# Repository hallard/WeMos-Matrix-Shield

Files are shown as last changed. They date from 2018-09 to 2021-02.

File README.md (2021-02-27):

# Basic ESP8266 WeMos Matrix Shield for Digital Morphing Clock

**This project has been deprecated** please check new version with ESP32 and DMA version [here](https://github.com/hallard/WeMos-Matrix-Shield-DMA)

This shield is used to get simplify ESP8266 connectivity with a [WeMos][22] ESP8266 and nice matric RGB led. This idea came from excellent project called [Morphing Digital Clock][3] done by [HariFun][1] Instructable

See it in action, nice isn't it?

**Pay attention V1.2 got a missing trace between Input and Output connector G1**
See Issue [#2](https://github.com/hallard/WeMos-Matrix-Shield/issues/2). and how to fix. If you have V1.2 don't forget to solder a wire between these 2 points (see below). Thanks to nthonyjclarke and dragondaud for pointing this out



This breakout has just few minimal features.

**New in V1.6**

- added experimetal support for ESP32 boards with WeMos Mini D1 wiring called ESP32 Mini Kit or ESP32 Wemos, or ESP32 MH-ET Live such as this [banggood model](https://www.banggood.com/Wemos-D1-Mini-ESP32-ESP-32-WiFiBluetooth-Internet-Of-Things-Development-Board-Based-ESP8266-p-1205854.html) or this [aliexpress](https://www.aliexpress.com/item/MH-ET-LIVE-D1-mini-ESP32-ESP-32-WiFi-Bluetooth-Internet-of-Things-development-board-based/32815530502.html). But you can find a lot also on ebay, not a problem.
- PCB board has been extented to fit this ESP32 Mini module but also backward compatible with WeMos Mini D1 ESP8266.

Please check wiring and picture before ordering, should looks like something like that:

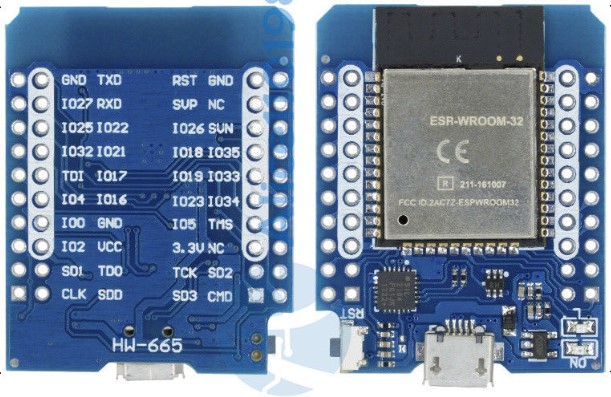
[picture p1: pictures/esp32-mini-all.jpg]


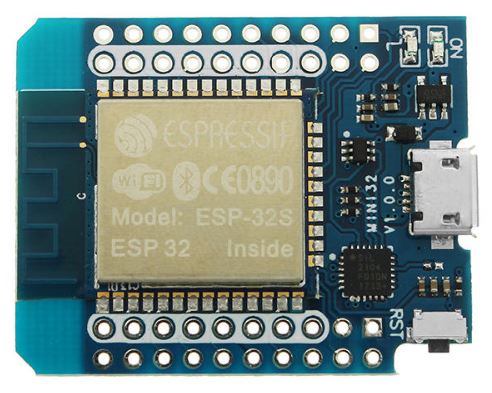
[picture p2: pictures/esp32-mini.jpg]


**New in V1.5**

- changed power connector spacing to fit the same than Matrix one's [#4](https://github.com/hallard/WeMos-Matrix-Shield/issues/4)
- added space for smaller Matrix power connector [#4](https://github.com/hallard/WeMos-Matrix-Shield/issues/4)
- generated [gerbers files](https://github.com/hallard/WeMos-Matrix-Shield/master/gerbers/)

**New in V1.4**

- Added DS18B20 footprint + 4K7 PullUp resistor (DS18B20 DQ connected to GPIO0/D3)
- Removed E connection to add DS18B20 (DQ PIN), added solder jumper if needed this connection back.
- added space for barrel DC connector if connector input connector is top soldered see [#3](https://github.com/hallard/WeMos-Matrix-Shield/issues/3)
- Changed LDR orientation

**New in V1.3**

- Fixed missing trace missing beetwen Input and Output connector G1. That was cutted by accident when creating V1.2 from V1.1.

**New in V1.2**

- Added footprint for a Photoresistor (LDR) + Resistor to be able to adjust luminosity with ambiant light
- This version has a missing trace between Input G0 and Output G1, connect a wire has follow to fix

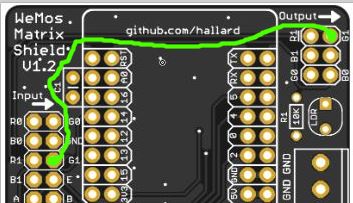
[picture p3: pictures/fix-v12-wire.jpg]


**New in V1.1**

- Power, added big connector 3.5mm spaced to put the supplied power cable
- Changed 3.5mm Phoenix connector by a 5mm one allowing the stronger power cable to fit info
- Moved output connector to the right you can use the supplied flat band connector
- Output connector can go straight to output connector of Matrix, allowing to use a 6 PIN ISP Arduino Like ribbon cable.
- Increased PCB traces width for 5V power
- Added some wiring info on bottom silk

**Still in V1.0+**

- DC Barrel power connector 
- Zero Press Fit power connector
- All necessary headers to connect the Matric Shield

WeMos provide 3 D1, [D1 Mini Lite][20], [D1 Mini][21] or [D1 Mini Pro][22].

**V1.0 boards are tested and working**. But it was missing B1 on 6 pin out connector, so you should grab it elsewhere, but it's now fixed on V1.1+ and also aligned out connector pins to the needed Matrix Order. You can order boards V1.4 at [PCBs.io][4]

# Detailed Description

Look at the schematics for more informations.

# Schematic  

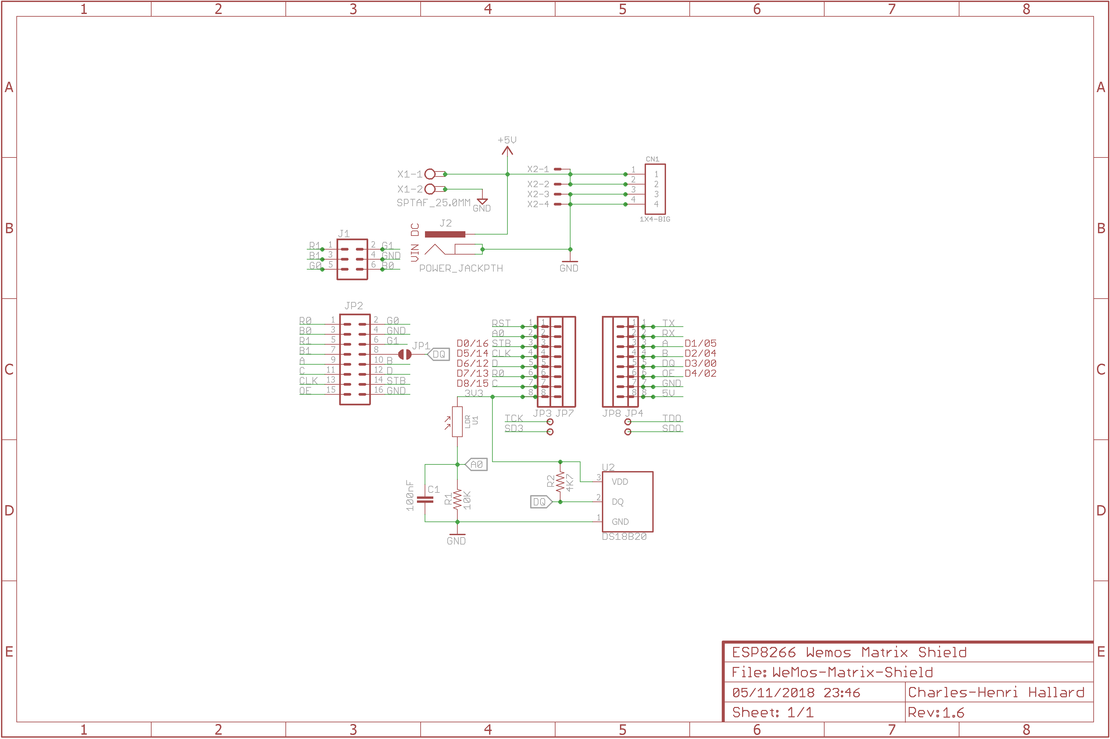
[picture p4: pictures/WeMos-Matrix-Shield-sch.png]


# Boards  

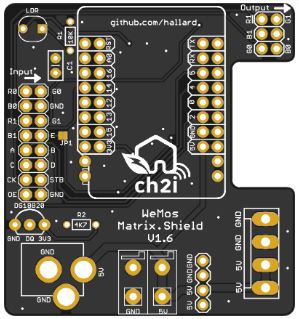
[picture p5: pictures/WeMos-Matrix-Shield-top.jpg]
Top
&nbsp;
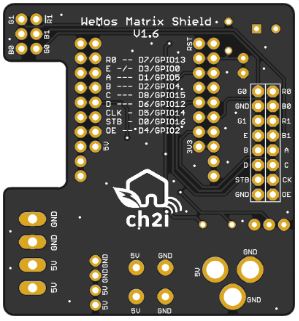
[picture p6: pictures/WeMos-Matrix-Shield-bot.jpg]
Bottom


You can order the PCB of this board at [PCBs.io][4]. PCBs.io give me some reward when you order my designed boards from their site. This is pretty good, because I can use these rewards to create and design new boards and order them for free, so if you don't care about PCB manufacturer please use PCBs.io.

# Firmware

I suggest to use the excellent code done by [dragondaud](https://github.com/dragondaud/myClock), it has all I wanted to do and mandatory feature, OTA and LDR Luminosity management.

# Assembled boards

Board have been made to be plugged directly on the matrix shield, see picture below:

Theese are pictures of the 1st PCB V1.0 with LDR Live Fix, just to see how are connected wire, I'm waiting new boards (V1.3), to take new pictures and show easier connecting.

**2x8 pins female connector is soldered on the bottom side of PCB**

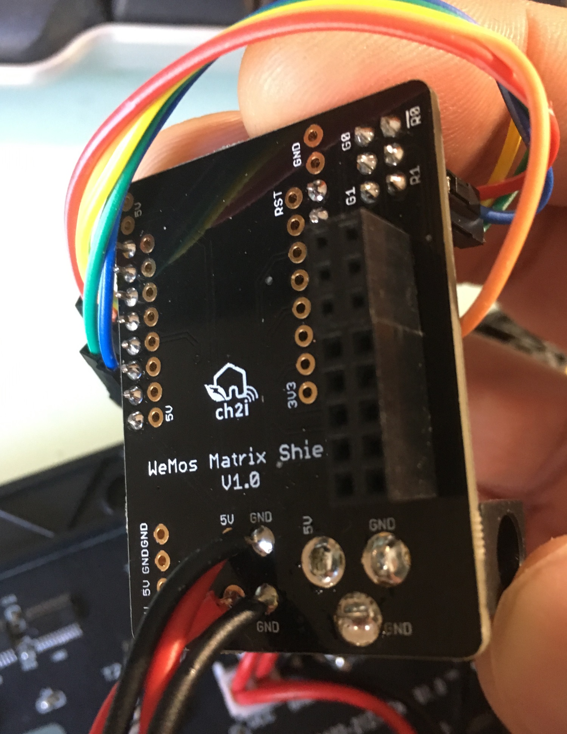
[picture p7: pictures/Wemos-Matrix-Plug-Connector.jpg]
Plug connector


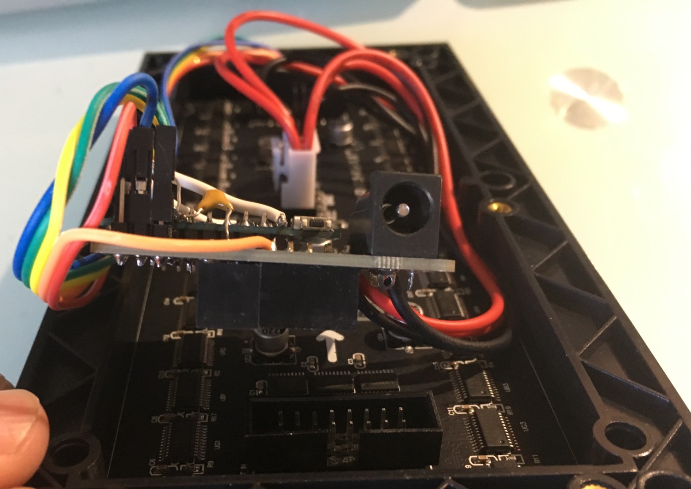
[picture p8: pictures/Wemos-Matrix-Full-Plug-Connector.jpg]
Plug connector on matrix


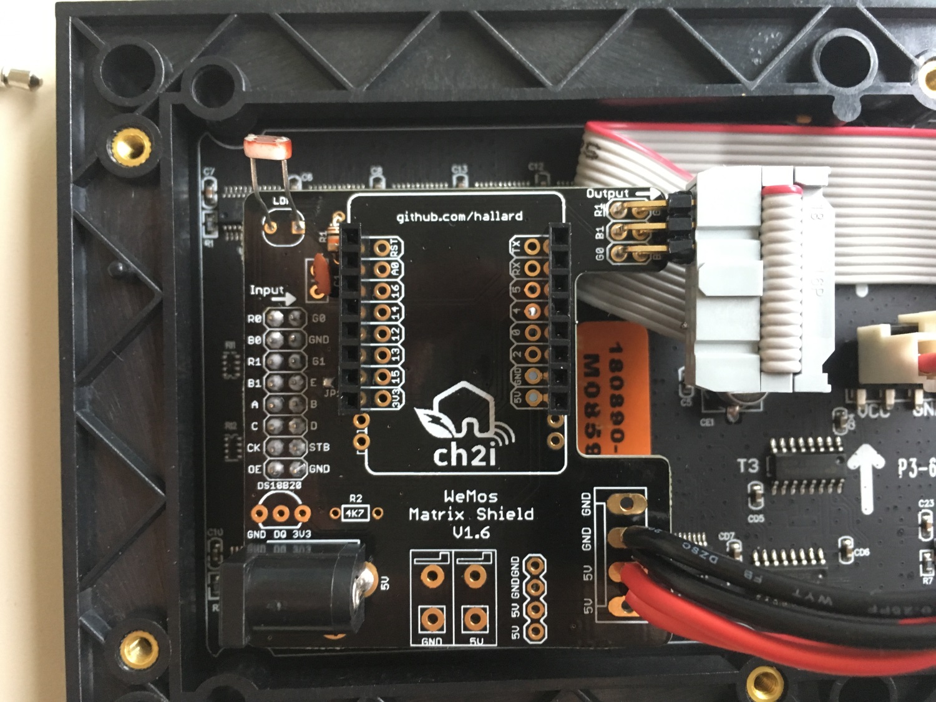
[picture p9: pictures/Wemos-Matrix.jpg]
PCB on matrix


**On this one you can see latest version with ESP32 MH-ET Live**

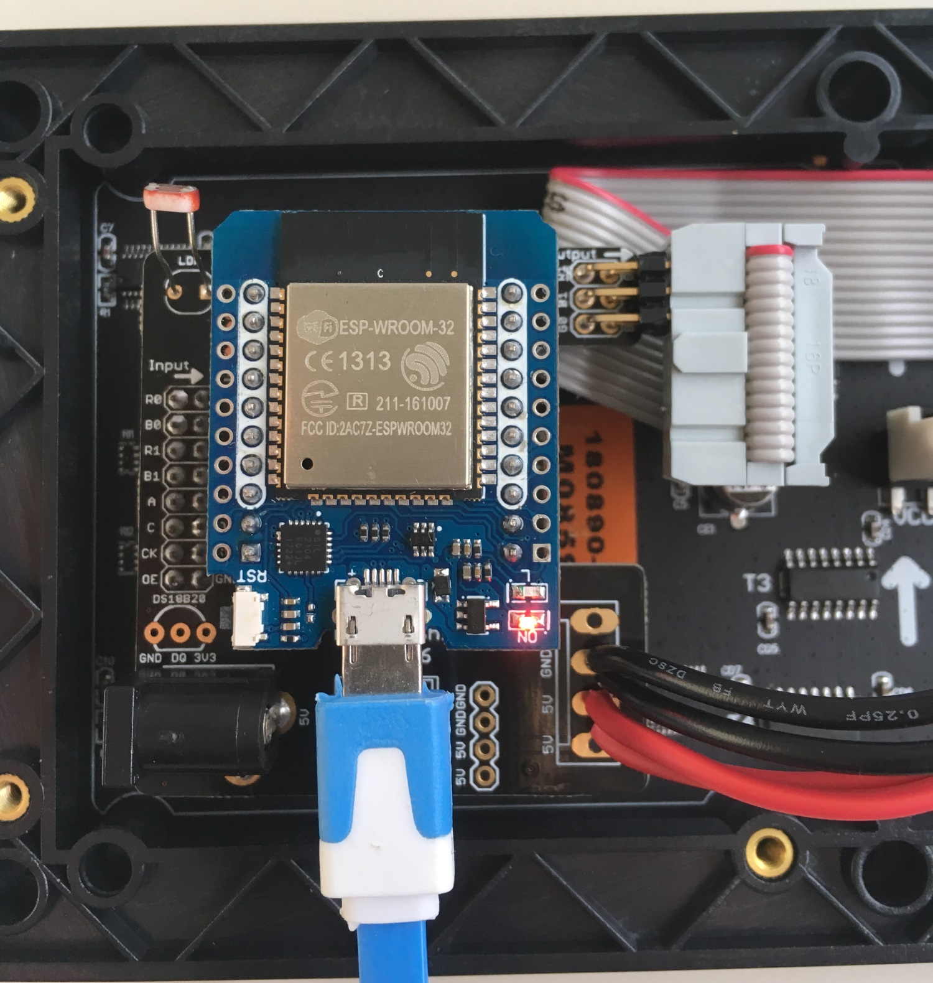
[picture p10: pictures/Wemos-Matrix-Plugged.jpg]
PCB plugged on matrix


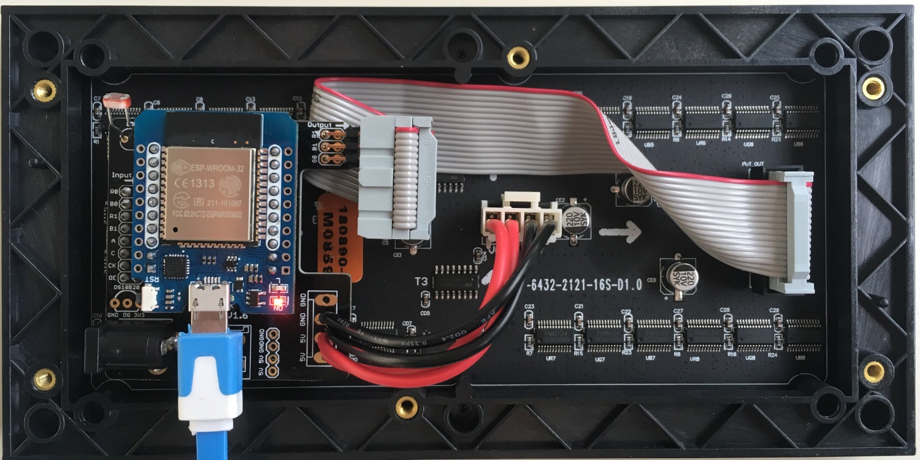
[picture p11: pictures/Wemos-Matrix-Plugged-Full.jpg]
PCB plugged on matrix, full board view


# BOM

Nothing fancy, just some headers and 2 differents power conector (choose the one you prefer) :

 - Ebay search for "DC Power Jack Barrel PCB Mount"
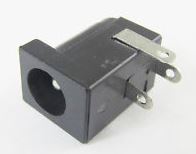
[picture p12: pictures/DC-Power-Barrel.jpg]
 
 - Phoenix contact PCB terminal block - SPTAF ref 1864286 (V1.0) or 1864435 (V1.1+) can be found anywhere
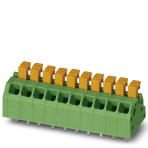
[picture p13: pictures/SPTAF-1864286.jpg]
 
- Ebay search for "2X8 Pin 2.54mm Double Row Female Header" or polulu product #1028, you can also use twice 1x8 pin female or even twice 2x4 pins female, plenty of option for this one
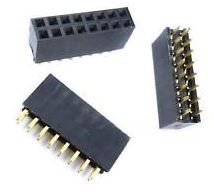
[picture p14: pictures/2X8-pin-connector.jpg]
 

# License

   

This work is licensed under a [Creative Commons Attribution-NonCommercial 4.0 International License](http://creativecommons.org/licenses/by-nc/4.0/)    

# Misc

See news and other projects on my [blog][2] 

Thanks to [HariFun][1] for this awesome stuff, please review and see how to build on [Instructable][3]
 
[1]: https://www.instructables.com/member/HariFun/
[2]: https://hallard.me
[3]: https://www.instructables.com/id/Morphing-Digital-Clock/
[4]: https://PCBs.io/share/rG9w7

[20]: https://wiki.wemos.cc/products:d1:d1_mini_lite
[21]: https://wiki.wemos.cc/products:d1:d1_mini
[22]: https://wiki.wemos.cc/products:d1:d1_mini_pro

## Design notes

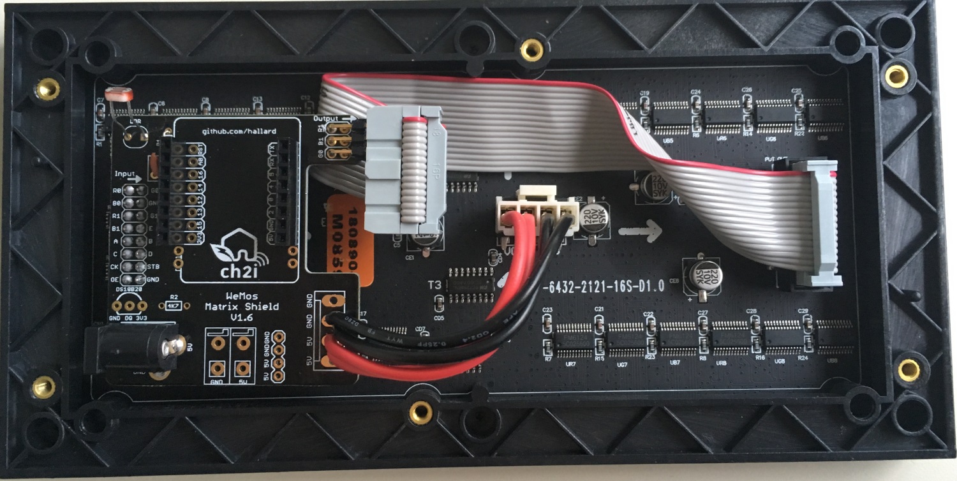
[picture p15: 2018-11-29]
pictures/Wemos-Matrix-Full.jpg

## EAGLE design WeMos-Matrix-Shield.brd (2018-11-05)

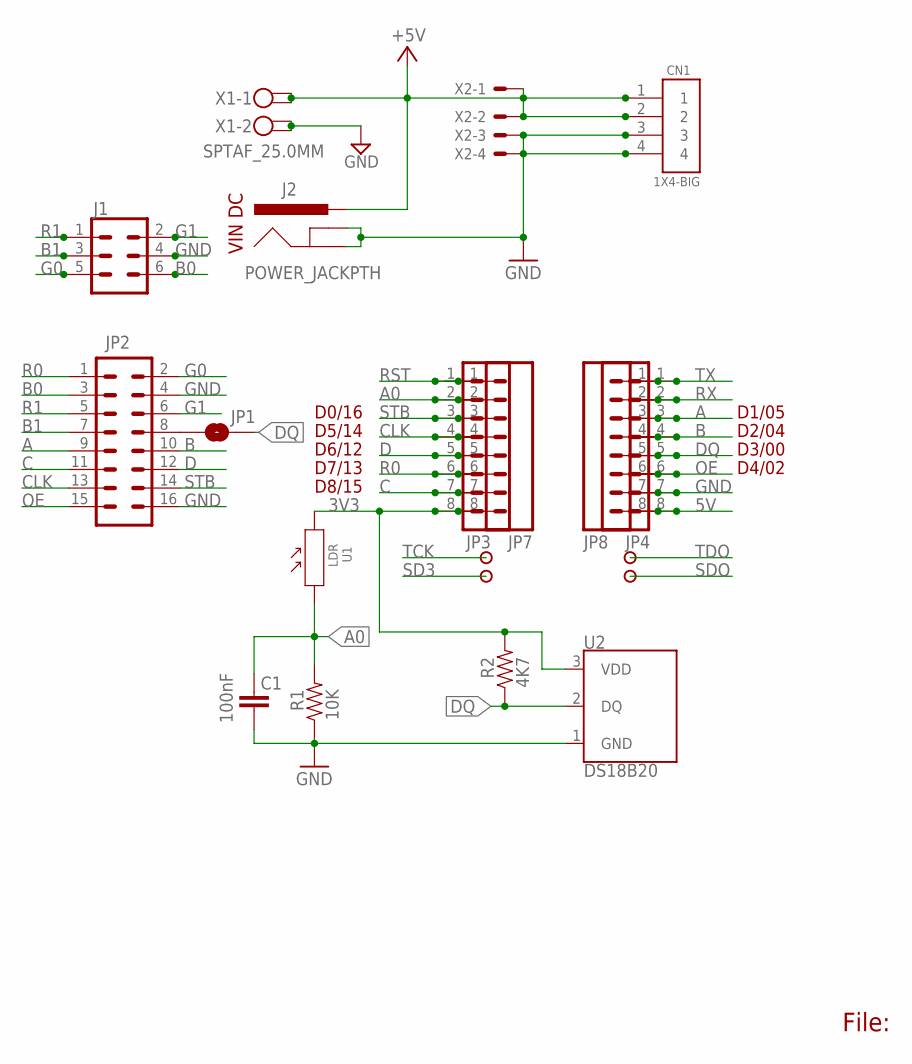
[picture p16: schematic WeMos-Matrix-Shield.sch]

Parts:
C1: 100nF; CAP-PTH-SMALL2
CN1: 1X4-BIG; 1X04-BIG
J1: CONN_03X22X3_SILK_MALE_PTH; 2X3
J2: POWER_JACKPTH; POWER_JACK_PTH
JP1: JUMPER-SMT_2_NO_NO-SILK; SMT-JUMPER_2_NO_NO-SILK
JP2: M08X2; 2X8
JP3, JP4, JP7, JP8: M08NO_SILK_FEMALE_PTH; 1X08_NO_SILK
R1: 10K; 1/6W-RES
R2: 4K7; 1/6W-RES
U1: LDR; SNR2-3.0
U2: DS18B20; TO-92-AMMO
VIN1, VIN2, VIN3, VIN4: PADNORMAL; PAD
X1: SPTAF_25.0MM; SPTAF_2X50
X2: KK-156-4

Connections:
3V3: JP3.8, JP7.8, R2.2, U1.2, U2.3 (VDD)
5V: CN1.1, CN1.2, J2.PWR, JP4.8, JP8.8, X1.1, X1.1A (2), X2.1, X2.2
A: JP2.9, JP4.3, JP8.3
A0: C1.1, JP3.2, JP7.2, R1.2, U1.1
B: JP2.10, JP4.4, JP8.4
B0: J1.6, JP2.3
B1: J1.3, JP2.7
C: JP2.11, JP3.7, JP7.7
CLK: JP2.13, JP3.4, JP7.4
D: JP2.12, JP3.5, JP7.5
DQ: JP1.2, JP4.5, JP8.5, R2.1, U2.2 (DQ)
G0: J1.5, JP2.2
G1: J1.2, JP2.6
GND: C1.2, CN1.3, CN1.4, J1.4, J2.GND, J2.GNDBREAK, JP2.4, JP2.16, JP4.7, JP8.7, R1.1, U2.1 (GND), X1.2 (1), X1.2A (2), X2.3, X2.4
unnamed: JP1.1, JP2.8
OE: JP2.15, JP4.6, JP8.6
R0: JP2.1, JP3.6, JP7.6
R1: J1.1, JP2.5
RST: JP3.1, JP7.1
RX: JP4.2, JP8.2
SD3: VIN4.1
SDO: VIN2.1
STB: JP2.14, JP3.3, JP7.3
TCK: VIN3.1
TDO: VIN1.1
TX: JP4.1, JP8.1

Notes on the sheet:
File:
D4/02
D3/00
D6/12
D2/04
D1/05
D7/13
D5/14
D8/15
D0/16
VIN DC

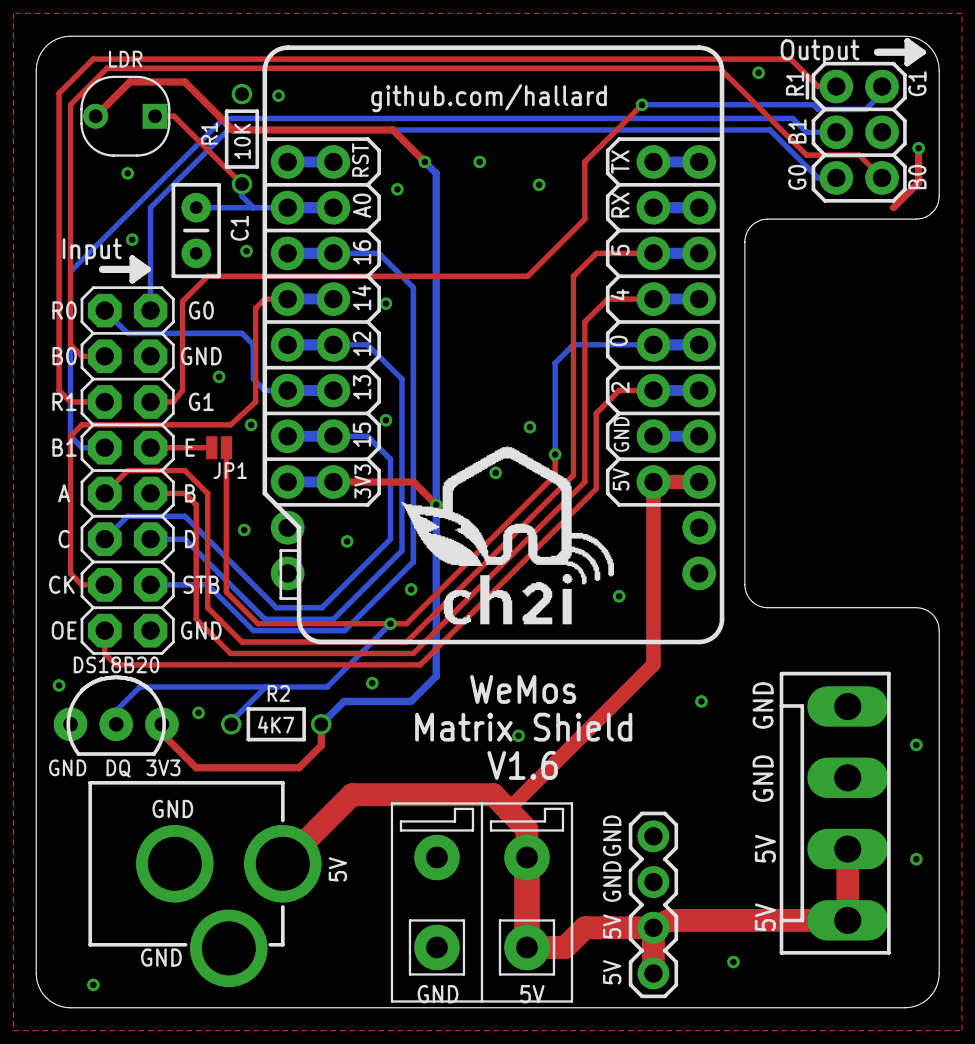
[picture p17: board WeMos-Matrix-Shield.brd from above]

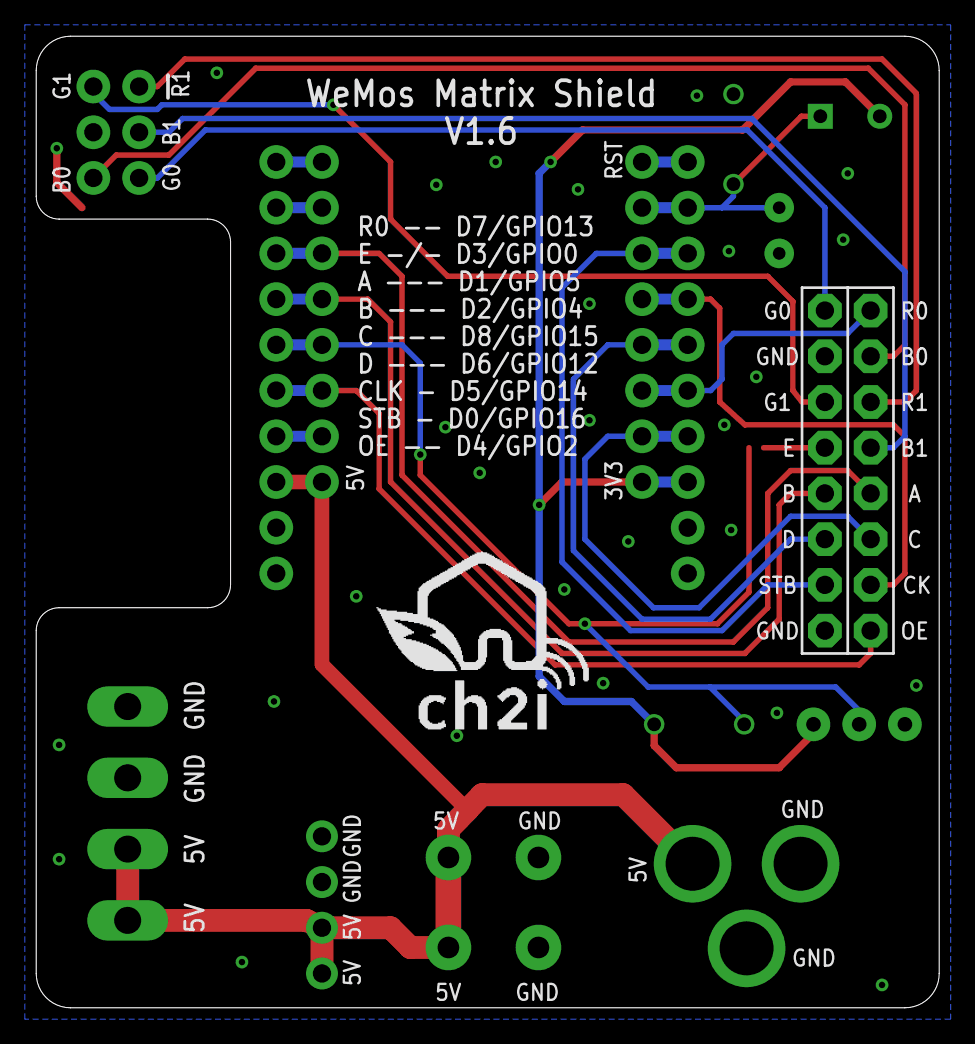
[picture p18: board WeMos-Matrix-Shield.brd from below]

Board: 2 copper layers, 50.2 x 54.0 mm, 22 parts (5 on the bottom side), 22 nets.

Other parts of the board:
U$1, U$3: LOGO_CH2I_110MM

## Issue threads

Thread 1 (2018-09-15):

v1.2 Boards from PCB.IO

anthonyjclarke, 2018-09-15:
Hi, great work BTW!

I recently ordered some, arrived but they are the v1.0 :( ... if I order again will they definitely be 1.2? ;-) If I look at the link - https://pcbs.io/share/zMPKb seems to show v1.0 boards?

hallard, 2018-09-15:
Thanks for pointing that, I'm sorry the link was the old one, they are 2 versions on PCBs.io, here is the correct link
https://PCBs.io/share/rG9w7
BTW, i fixed the repo also

Closed 2018-09-15.

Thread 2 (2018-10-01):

Wiring / Assembling issues

anthonyjclarke, 2018-10-01:
Ordered some 1.2 boards and not having any success wiring up, spent a few hours on this.

Wondering if you have used / have any photos to share?

Seems, I think, my issue is the J1 connector.  The pins on the PCB :-

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

Dont seem to align with Hari's image from his instructable site,

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

Is there an issue here as I cannot see R0?

hallard, 2018-10-01:
I do not have received yet the 1.2 boards, so I can't test at all
The J1 connector should go straight to the output of the Matrix Board with a 6 pin ISP Connector

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

And yes the trick is that it's not aligned (was my error on PCB 1.0)
As you can see, J1 is matrix in pinout going to matrix out
in the example:

 - J1 pin 1 (so R1 for matrix in) goes to matrix out pin R0 according the following table
 - J1 pin 6 (so B0 for matrix in) goes to matrix out pin G1 according the following table

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

I must admit it gave me some headaches ;-)

anthonyjclarke, 2018-10-01:
Thanks. I will try again tomorrow.

Do you have any photos showing a built PCB and all wired up?

anthonyjclarke, 2018-10-01:
I had to buy 10 PCB's, dont need them all, to thank you for your effort I'm happy to post you some if you want to DM your postal address? Can send today...

anthonyjclarke, 2018-10-03:
I had to buy 10 PCB's, dont need them all, to thank you for your effort I'm happy to post you some if you want to DM your postal address? Can send today...

dragondaud, 2018-10-05:
Verified: adding wire from G1 input to the pin labeled G1 (which goes to G0) on output fixes board, and it now works great.

hallard, 2018-10-06:
@dragondaud, @anthonyjclarke
thanks for reporting, I fixed this error. Amazing checked on V1.1 boards, and trace was there, a bad cut on eagle when creating V1.2 and voilà. Here is the visual fix

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

Anyway it's now fixed in V1.3, links and documentation has been updated and also PCBs.io boards.

@dragondaud  just saw your firmware, all I wanted to do, so thanks a lot, I'll try it ASAP

Thanks to @anthonyjclarke for the PCB, but I already have a lot here, so I don't need them  ;-)

Closed 2018-10-21.

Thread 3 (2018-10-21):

v1.4 "Enhancement" Request!

anthonyjclarke, 2018-10-21:

hallard, 2018-10-21:
Updated Repo and PCBs.io to V1.4

dragondaud, 2018-10-21:
Ah, when I first received my v1.2 boards there wasn't much information on assembly, so I just winged it.... Attaching directly seems like a great idea. I will update the BOM in myClock for that configuration. :)

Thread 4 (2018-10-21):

Power Header for PCB

anthonyjclarke, 2018-10-21:
Hi

Thanks for all your Dev here, brilliant.. you should have a "Tip Jar" :)

Will order some 1.4 boards, before I do... I noticed that the Power Headers I bought from Aliexpress - http://tinyurl.com/y7eymwsj do not seem to fit the PCB.  They align with the Power Cable from the displays I have.

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

Is this my error in ordering? or the wrong connector on the PCB?

Thanks

anthonyjclarke, 2018-10-22:
No need to send, I will order when you have updated the PCB :)

Really appreciate your help here!

Built another version today... using a more compact LED display - P2.5 64x32 http://tinyurl.com/ycgdvj3t , so may have to think about the display connector again...

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

Bit too close to the power connector...

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

:)

hallard, 2018-10-22:
Damned, it will start to be complicated
best would be to be able to plug also on the power connector ;-)

anthonyjclarke, 2018-10-24:
@hallard Could I please ask a big favour :)
Going to order from jlcpcb.com some 1.4 boards (quicker than pcb.io)
They have just told me the gerbers I created from Eagle are not valid, is there any way you could export gerber files and share (please) ? :)

hallard, 2018-10-26:
@anthonyjclarke
I'm using Eagle Also, that' strange, default settings doesn't work. Which CAM job did you used? does jlcpcb provide any cam job to generate gerbers?
Anyway I've put gerber file on the repo (used SeeedStudio CAM file) and that's for version V1.5 that should fix you issues ;-)
Let me know if gerbers are ok.

anthonyjclarke, 2018-10-26:
@hallard Thanks for this... Looks perfect, like the new version... *IF* there ever is a 1.6 then I've had some issues in Temp Sensors being so close to the Wemos / perhaps move that to the outside of the board.... I may mount on wire in any case.  Thanks again!

dragondaud, 2018-10-27:
I'v been using [waterproof DS18B20](http://a.co/d/5qSImdf) which come on a long wire, but I put clocks inside shadow box frames, and I wanted the temp sensor outside of that, even.

hallard, 2018-10-31:
Yes, I had some problem with NodeMCU board when I but SI7021 on board shield sensor, temp sensor need to be far from CPU board, because value is higher than real.
May be adding an "offset" option could help, but the best is the DS18B20 waterproof, just a hole in the case to get sensor out.

Closed 2018-10-31.

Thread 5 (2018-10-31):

Typo in readme

dragondaud, 2018-10-31:
Under "New in V1.4" is says "Added DS18B20 footprint + 4K7 PullUp resistor (DS18B20 DQ connected to GPIO0/D7)", but GPIO0 is D3 (not D7).

hallard, 2018-10-31:
Absolutely, thanks for pointing out, it's fixed now.

Closed 2018-10-31.

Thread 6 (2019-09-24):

pcbs.io gone?

dragondaud, 2019-09-24:
I placed an order for more of your boards on July 26th with pcbs.io. They took my money and sent email stating "Your PCBs.io Order has been placed! Your order will ship in about 10-14 days. We will send you a shipment email when this occurs."

They have not shipped the order, do not respond to emails, and haven't responded to PayPal dispute messages.

FYI

hallard, 2019-09-24:
Hi

That’s a shame, what’s the status of your order when you connect to your account ? I Placed an order last week

But you see some of my old orders are still in fabrication and I received them, that’s so strange

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

hallard, 2019-09-24:
I got some V1.4 and V1.5 spare around there, give me your postal address, I will arrange shipment.

dragondaud, 2019-09-27:
This order was placed on Jul 26, 2019, 2:47 PM, and I'v emailed several times with no response.
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
I don't have an urgent need, but wanted to try the v1.6 board. I'll just send an order elsewhere. :)

dragondaud, 2019-09-27:
I just checked, and you are right about status not updating. Previous order I did receive does still show In Fabrication, too. They haven't responded to PayPal, either, so PayPal will take my money back from them, sometime soon.

helmarw, 2019-10-26:
i ordered mine here: https://aisler.net
21€ for 3

anthonyjclarke, 2019-10-31:
I went hunting for my 1.6 boards, sure I ordered them... I did!  Same for me, never arrived... did @dragondaud have any success in a refund?

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

dragondaud, 2019-11-01:
I did receive my refund from PayPal, never heard anything from pcbs.io, nor
did PayPal.

On Thu, Oct 31, 2019 at 2:12 PM Anthony Clarke <notifications@github.com>
wrote:

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

--
david denney
dragondaud AT gmail DOT com
719-821-8900

hallard, 2020-08-08:
Guys,

just to let you know that PCBs.io are still working, I received a big batch of PCB and the v1.7 is on the road.

Alexisgm7, 2020-09-09:
Hello everyone, I came across this conversation and I am glad to hear that PCBs.io are still working as Hallard said but I tried to make an order today September 9 and their paying platform gives an error as I can't pay with Paypal nor with a credit card.

This is the message that appears: Failed to connect to Paypal. You have not been charged. Please try again.

Does someone have the same issue?  I have already sent them a message, I will have to wait for their response.

Cheers

loeffma, 2020-09-23:
Hello from Germany.

I have the same problem. Their paying platform gives an error as I can't pay with Paypal nor with a credit card.
@Alexisgm7 : Do you get any response from PCBs.io?
@hallard : Where can I get the PCB for "LoRa shield for WeMos D1 mini boards" also?

Best regards

Alexisgm7, 2020-09-23:
Hello!

No, I haven't received any reply. And I contacted them via 3 different email adresses I found.

Cheers

loeffma, 2020-09-23:
Okay. And what does that mean? Is pcbs.io "dead"?
I also don't find an adress on the homepage. I think that's strange ...

hallard, 2020-09-23:
I'm afraid they're down, I looked at my reward and don't see any new order since august 10th, got 3 orders waiting for panelization, so if you're un hurry I suggest moving to oshpark.

loeffma, 2020-09-23:
Do you have a link to the "LoRa shield for WeMos D1 mini boards" on oshpark?

hghile, 2020-09-24:
I've been ordering from pcbs.io on and off over the years, and I've emailed them on multiple occasions and have never ever gotten a single response.  It is incredibly hard to tell if they are still functional.  A few months back, probably a bit earlier than this issue opened, I attempted to order some boards and there was a javascript error preventing payment from loading.  I sent them an email about it (no answer).  I used developer tools and worked around the error, and submitted an order, it appeared to go through.  I sent them an email about how to fix their error.  (no answer) I waited a few weeks, status didn't change, I figured they were dead.  But, a week later, the status said the board went to fab!  then a week later it was back to saying awaiting panelization.  But then it went back to fab, and maybe 5 weeks after placing the order, boards showed up.  And the javascript error got fixed.  pcbs.io was still functional!
But now I can't place orders again.  I hope they aren't gone.  They're good quality and cheap.  oshpark service is way better, but I like saving a few bucks.  I could email them and ask if they're going to fix the payment system, but I expect no answer.

feiticeir0, 2021-02-22:
I'm trying to place an order and I can't... Paypal or credit card is not working... Is there another place to order this PCB ?

hallard, 2021-02-22:
You can order to oshpark, I need to update readme with that link
https://oshpark.com/shared_projects/bzjXuzgQ

If you're in a hurry I got some spare here in France.

Sean-Ocansey, 2021-04-14:
Do you guys know if this service will ever come back? I would really like some Black and gold 1.2mm PCB at a good price. I heard the owner was thinking about selling the business, do you know if there are any buyers interested?

frederic-kleinert, 2022-12-11:
> Ich habe meine hier bestellt: https://aisler.net 21€ für 3 Sie können diesen Link verwenden: https://aisler.net/p/DRGKVMVA

Hallo!
Wie bestellt man bei Aisler? Ich komme nicht zurecht.
Danke!

helmarw, 2022-12-12:
WTF, looks like they broke something. i cant order some of my own projects (which i ordered already a while ago)
and some others i can.
I do not recommend Aisler anymore, we had a lot of problems with them last year.
Their QM sucks, at least it did a year and a half ago, and it was with Assembly, had really a fun time with that :/
that said simple PCBs are ok more or less, you get what you pay for.

1)one quick workaround i found is refreshing the webpage a couple of times and suddenly i could click on order.
2)if this doesn't work, after clicking import, download the file first (symbol left upper corner), maybe rename it
and add it as you own project, still might need to ways a bit after upload and refresh webpage.
3)take the gerber.zip form this repository and add it to your Aisler profile, same rules apply, wait a bit and refresh

frederic-kleinert, 2022-12-14:
Danke!
Die Bestellung hat endlich funktioniert.
Wenn nun die Lieferung im Januar auch eintrifft, ist alles in Ordnung.

Closed 2020-08-08.

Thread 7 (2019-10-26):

MH-ET LIVE D1 mini wiring "issues"

helmarw, 2019-10-26:
not per se an issue just more an information for ppl want to use MH-ET LIVE D1 mini.
Took me a couple of nights to figure it out and to get it to work. The general pin layout is the same but there is a tiny bit of information missing, the IOs are completely different to the WeMos.
Neither https://github.com/dragondaud/myClock nor the PxMatrix library https://github.com/2dom/PxMatrix are working out of the box. Even SPI interface is on different IOs. I tried to summarise my modification in the attached pdf. Nothing fancy and i had to modify PxMatrix.h but it works now.
i use a p4 64x32 Matrix display e.g. https://de.aliexpress.com/item/32380311346.html
and those ESP32 https://de.aliexpress.com/item/32815530502.html
This display seems to have a slow muxer so i had to use setMuxDelay, which is not part of the
standard Arduino library v1.3.0 (installed form the library manager). The GitHub version v1.5.0
didnt work for me at all, so i added only the SPI and setMuxDelay-Modifications to the v1.3.0
also attached. then of course i needed to modify display.h and myclock.ino

[MH-ET Live Minikit pinout and mods for LED Matrix.pdf](https://github.com/hallard/WeMos-Matrix-Shield/files/3774625/MH-ET.Live.Minikit.pinout.and.mods.for.LED.Matrix.pdf)
[PxMatrix_mod.txt](https://github.com/hallard/WeMos-Matrix-Shield/files/3774630/PxMatrix_mod.txt)
You can use those files as reference. rename and replace PxMatrix.h with my mod, if you have
the same issue

hallard, 2020-08-08:
Thank for the head up, as for today, I'm using this code that works on ESP8266 and ESP32 with this shield.

```cpp
#if defined(ESP8266)

#define P_LAT 16
#define P_A 5
#define P_B 4
#define P_C 15
#define P_D 12
#define P_E 0   // not needed on 64x32
#define P_OE 2

#elif defined(ESP32)

#define SPI_CLK 18
#define SPI_MOSI 23
#define SPI_MISO 19
#define SPI_SS 5

#define P_LAT 26
#define P_A 22
#define P_B 21
#define P_C 5
#define P_D 19
#define P_E 17  // not needed on 64x32
#define P_OE 16

#else

#error "Target not supported, please select a ESP8266 or ESP32 Board"

#endif

```

and yes on my latest displays I needed to add this line also
```cpp
//added for slow muxer
display.setMuxDelay(1,1,1,1,1);
```

Closed 2020-08-08.

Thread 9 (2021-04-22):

Panel is not working - issues with assembly - no instructions ?

feiticeir0, 2021-04-22:
Hi Hallard !

First, thank you for the shield. I've ordered 3 from OSHPark. They are version 1.6

I've assembled one, with what I could gather from github - both from version with and without DMA.
I'm using Wemos D1 mini ESP8266.
I just see a random streaks of lines on the display.
I've used 32x32 and 64x64 . I have 32x64, but haven't tested them.

I've tested with PXMatrix (the ESP32-HUB75-MatrixPanel-I2S-DMA is just for ESP32). I don't have any ESP32 Wemos like the ones you've described . I do have ESP32, but not wemos.

Any hint what could it be or how to assemble this version 1.6 ?
I've used - don't know if it's ok or not, 10K resistor and 4.7K resistors. soldered an LDR, a 100uF capacitor (haven't soldered this one yet - it's placed there - because there's no hint on what's the negative side and the positive one - at least none that I can see).

Thank you

hallard, 2021-04-22:
Would be helpfull to help if you could post a picture of what you've done.

This version works only with PXMatrix because wiring is not for ESP32-HUB75-MatrixPanel-I2S-DMA (even if you use an ESP32). For use [this version](https://github.com/hallard/WeMos-Matrix-Shield-DMA)

To do tests, you just need to solder the headers no components needed (except ESP of course). Better to add caps if ESP goes into reset.

feiticeir0, 2021-04-25:
Hi Hallard.
I'm going to close the issue.

I was hopping for some feedback, but I managed to solve this one.  The assembly is well done. My problem is that I had some wemos d1 mini with the sleep solder blob on and that was messing the code and the wemos d1 somehow.  Removing the solder on the PAD solve the issues.  I discover because I've tried with another wemos I have around and worked perfectly. I've tested with 32x32 and 64x32 panels and both worked wonderfully.
Thank you

hallard, 2021-04-25:
Glad you had it working.

You need to remove big capacitor, it will really slow down light change, this one should be 100nF (unpolarized) only, but you also can remove completely and just let 10K resistor and LDR.

Closed 2021-04-25.

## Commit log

2018-09-09 Bump to V1.1
    [WeMos-Matrix-Shield.brd, WeMos-Matrix-Shield.sch]
2018-09-11 Update to V1.2
    [WeMos-Matrix-Shield.brd, WeMos-Matrix-Shield.sch]
2018-09-15 Fixed PCBs.io link
2018-10-06 Updated to V1.3
    [WeMos-Matrix-Shield.brd, WeMos-Matrix-Shield.sch]
2018-10-21 Added mounting pictures
2018-10-21 Added 2x8 pin connector on BOM
2018-10-21 Added connector picture
2018-10-21 Updated to V1.4
    [WeMos-Matrix-Shield.brd, WeMos-Matrix-Shield.sch]
2018-10-26 Updated to V1.5
    [WeMos-Matrix-Shield.brd, WeMos-Matrix-Shield.sch]
2018-10-31 Typo between D7/D3 for DQ pin
2018-11-05 V1.6 Gerbers
    [WeMos-Matrix-Shield.GBL, WeMos-Matrix-Shield.GBO, WeMos-Matrix-Shield.GBP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]
2018-11-05 Updated to V1.6
    [WeMos-Matrix-Shield.brd, WeMos-Matrix-Shield.sch]
2018-11-29 ESP32 Version
2026-04-29 Switch to CC BY-NC-SA 4.0 license, add LICENSE file

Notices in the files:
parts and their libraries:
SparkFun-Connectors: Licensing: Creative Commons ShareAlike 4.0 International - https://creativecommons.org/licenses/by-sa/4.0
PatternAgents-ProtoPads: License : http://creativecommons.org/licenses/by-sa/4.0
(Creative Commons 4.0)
